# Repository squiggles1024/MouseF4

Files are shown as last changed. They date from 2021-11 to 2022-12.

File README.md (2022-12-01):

# Custom Gaming Mouse Project

One of my earlier embedded systems projects. A custom gaming mouse with up to 22 programmable buttons. The firmware is a bit rough around the edges, but I learned a lot about wired USB in the process of coding it.
I wrote a short Python script that communicates new settings to a USB endpoint dedicated to this purpose. 

This iteration implements 14 buttons, a mouse wheel, programmable DPI from 100 to 10000, a tricolored LED with 4 flashing modes, and button keybinds saved in an eeprom.
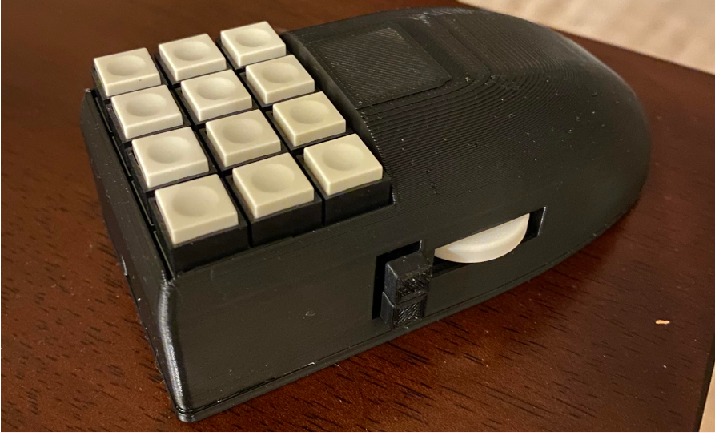
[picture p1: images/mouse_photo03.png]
Final Product


PCB is my own design featuring an STM32F4 microcontroller which I flashed using a J-Link SEGGER. The PMW3360 motion sensor was purchased as a COTs module. I would have liked to include this on the main PCBA, but the manufacturer was unrespsonsive to my emails and they don't stock the part openly at online retailers like digikey and mouser. The complete BOM and schematics are part of this repository
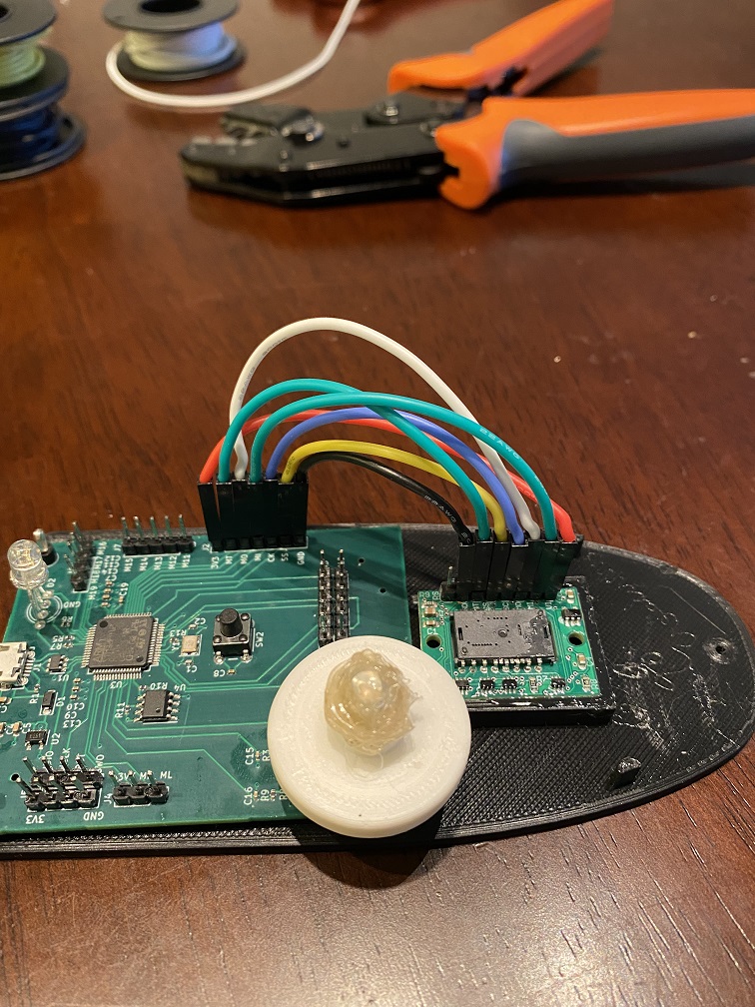
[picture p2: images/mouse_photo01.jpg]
PCB Design


The 3D printed housing (also my design) was glued to the base plate with E6000. Not a particularly robust mechanical design, but it worked for me. The main issue with this is that, because I didn't write a custom bootloader, the device can no longer be programmed again. This isn't a huge issue, but the mouse wheel you see in the photo is actually "backwards" (Scrolling forward will scroll down, and scrolling backward will scroll up). This is an easy firmware fix, but I can no longer access the JTAG pins or BOOT switch. 
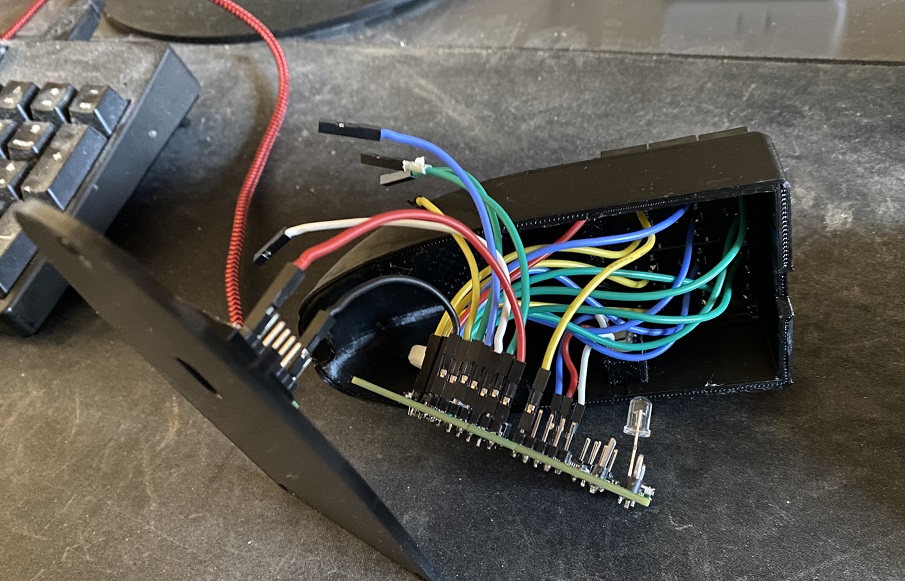
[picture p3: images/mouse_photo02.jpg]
Assembly


The LED can't really be seen in normal operation, though it can serve as a visual cue that new settings were successfully programmed when changing the keybinds using the python script.
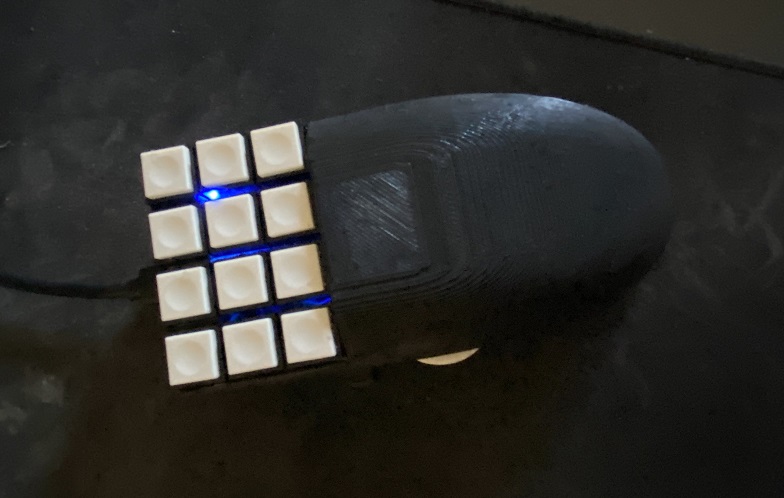
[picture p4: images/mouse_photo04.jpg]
LED


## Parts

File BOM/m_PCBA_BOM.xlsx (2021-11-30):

Comment | Designator | Footprint | JLCPCB Part #（optional） | Other PN
12pF | C1 | Capacitor_SMD:C_0402_1005Metric | C26406
12pF | C2 | Capacitor_SMD:C_0402_1005Metric | C26406
100nF | C3 | Capacitor_SMD:C_0603_1608Metric | C14663
1uF | C4 | Capacitor_SMD:C_0603_1608Metric | C15849
100nF | C5 | Capacitor_SMD:C_0603_1608Metric | C14663
1uF | C7 | Capacitor_SMD:C_0402_1005Metric | C52923
100nF | C8 | Capacitor_SMD:C_0402_1005Metric | C307331
100nF | C9 | Capacitor_SMD:C_0402_1005Metric | C307331
100nF | C10 | Capacitor_SMD:C_0402_1005Metric | C307331
100nF | C11 | Capacitor_SMD:C_0402_1005Metric | C307331
100nF | C12 | Capacitor_SMD:C_0402_1005Metric | C307331
100nF | C13 | Capacitor_SMD:C_0402_1005Metric | C307331
4.7u | C14 | Capacitor_SMD:C_0402_1005Metric | C23733
10nF | C15 | Capacitor_SMD:C_0402_1005Metric | C15195
10nF | C16 | Capacitor_SMD:C_0402_1005Metric | C15195
4.7u | C19 | Capacitor_SMD:C_0402_1005Metric | C23733
B5819W | D1 | Diode_SMD:D_SOD-123 | C8598
LED_RCGB | D2 | LED_THT:LED_D5.0mm-4_RGB_Wide_Pins |  | COM-00105
LED | D3 | Diode_SMD:D_0603_1608Metric | C2286
USB_B_Micro | J1 | Connector_USB:USB_Micro-B_Molex-105017-0001 | C132563
Conn_01x07 | J2 | Connector_PinHeader_2.54mm:PinHeader_1x07_P2.54mm_Vertical
Conn_02x06_Odd_Even | J3 | Connector_PinHeader_2.54mm:PinHeader_2x06_P2.54mm_Vertical
Conn_01x03 | J4 | Connector_PinHeader_2.54mm:PinHeader_1x03_P2.54mm_Vertical
Conn_02x04_Odd_Even | J5 | Connector_PinHeader_2.54mm:PinHeader_2x04_P2.54mm_Vertical
Conn_01x04 | J6 | Connector_PinHeader_2.54mm:PinHeader_1x04_P2.54mm_Vertical
Conn_01x05 | J7 | Connector_PinHeader_2.54mm:PinHeader_1x05_P2.54mm_Vertical
100k | R1 | Resistor_SMD:R_0402_1005Metric | C25741
10k | R2 | Resistor_SMD:R_0402_1005Metric | C25744
10k | R3 | Resistor_SMD:R_0402_1005Metric | C25744
10k | R4 | Resistor_SMD:R_0402_1005Metric | C25744
470 | R5 | Resistor_SMD:R_0402_1005Metric | C25117
470 | R6 | Resistor_SMD:R_0402_1005Metric | C25117
470 | R7 | Resistor_SMD:R_0402_1005Metric | C25117
10k | R8 | Resistor_SMD:R_0402_1005Metric | C25744
10k | R9 | Resistor_SMD:R_0402_1005Metric | C25744
4.7k | R10 | Resistor_SMD:R_0402_1005Metric | C25900
4.7k | R11 | Resistor_SMD:R_0402_1005Metric | C25900
510 | R12 | Resistor_SMD:R_0402_1005Metric | C25123
47 | R13 | Resistor_SMD:R_0402_1005Metric | C25117
SW_SPDT | SW1 | Button_Switch_SMD:SW_SPDT_PCM12 |  | PCM12SMTR
SW_Push | SW2 | Button_Switch_THT:SW_PUSH_6mm_H5mm |  | Any 6x5 push button
Rotary_Encoder_Switch | SW3 | Rotary_Encoder:RotaryEncoder_Alps_EC11E-Switch_Vertical_H20mm |  | EC11E09244AQ
USBLC6-2SC6 | U1 | Package_TO_SOT_SMD:SOT-23-6 | C7519
STLQ015M33R | U2 | Package_TO_SOT_SMD:SOT-23-5 | C136154
STM32F412RETx | U3 | Package_QFP:LQFP-64_10x10mm_P0.5mm | C89374
CAT24C32WI-GT3 | U4 | Package_SO:SOIC-8_3.9x4.9mm_P1.27mm | C81193
Crystal_GND24 | Y1 | Crystal:Crystal_SMD_3225-4Pin_3.2x2.5mm | C13738

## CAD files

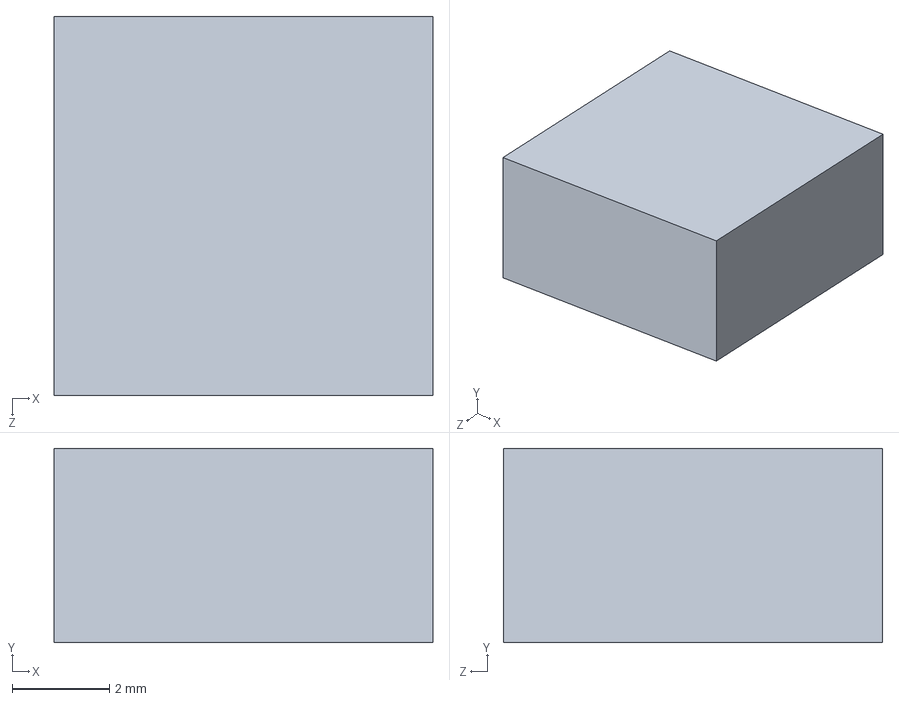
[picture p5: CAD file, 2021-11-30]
MCAD/keycaps3.SLDPRT
7.80 x 4.00 x 7.80 mm

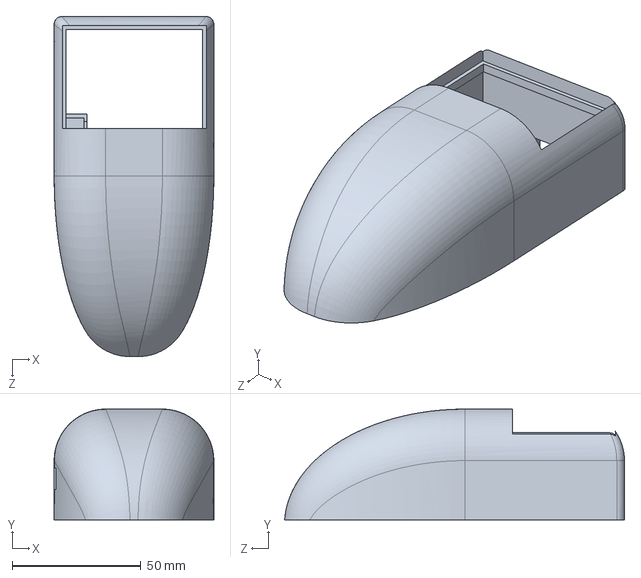
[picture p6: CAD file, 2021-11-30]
MCAD/mouse_housing.SLDPRT
62.0 x 43.0 x 132.0 mm

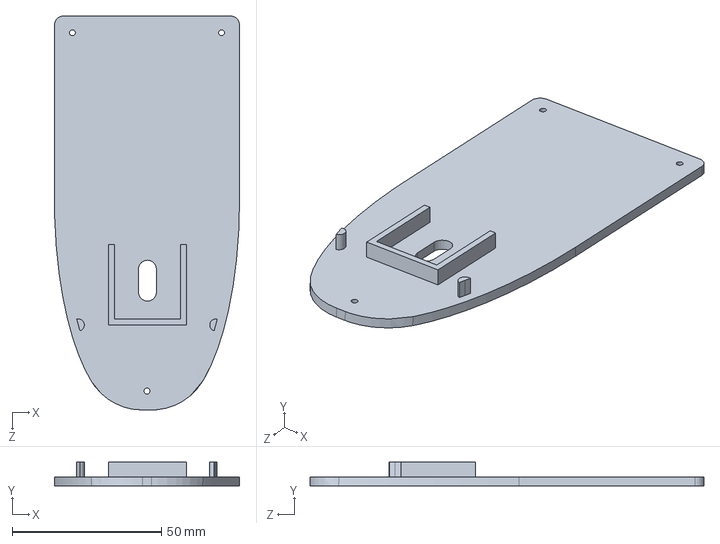
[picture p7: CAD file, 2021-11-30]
MCAD/mouse_base.SLDPRT
62.0 x 8.00 x 132.0 mm

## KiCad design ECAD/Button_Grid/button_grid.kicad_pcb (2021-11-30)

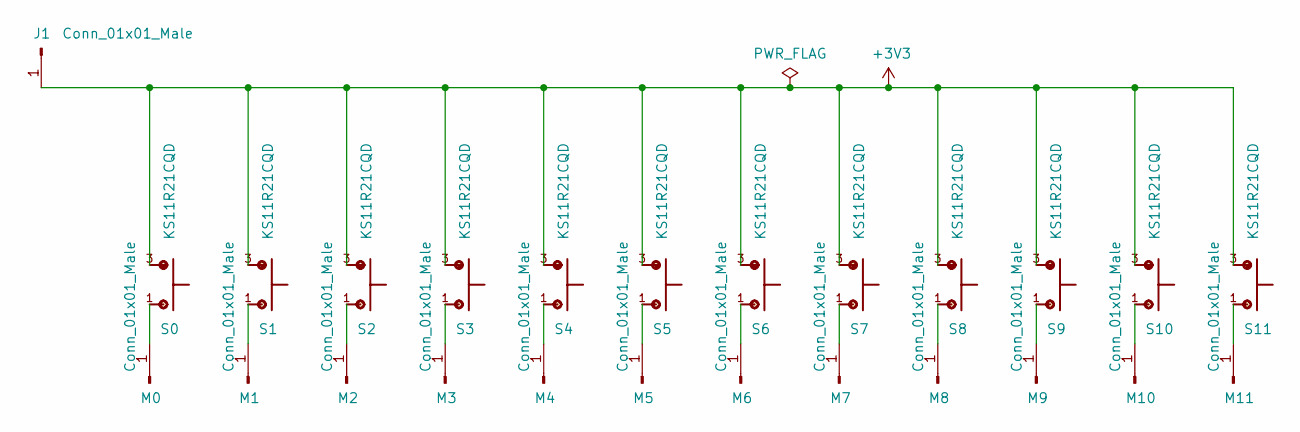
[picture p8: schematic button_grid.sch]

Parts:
J1: Conn_01x01_Male; PinHeader_1x01_P2.54mm_Vertical
M0, M1, M2, M3, M4, M5, M6, M7, M8, M9, M10, M11: Conn_01x01_Male; PinHeader_1x01_P2.54mm_Vertical
S0, S1, S2, S3, S4, S5, S6, S7, S8, S9, S10, S11: KS11R21CQD; SW_KS11R21CQD

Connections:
+3V3: J1.1, S0.3, S1.3, S2.3, S3.3, S4.3, S5.3, S6.3, S7.3, S8.3, S9.3, S10.3, S11.3
unnamed: M0.1, S0.1
unnamed: M1.1, S1.1
unnamed: M2.1, S2.1
unnamed: M3.1, S3.1
unnamed: M4.1, S4.1
unnamed: M5.1, S5.1
unnamed: M6.1, S6.1
unnamed: M7.1, S7.1
unnamed: M8.1, S8.1
unnamed: M9.1, S9.1
unnamed: M10.1, S10.1
unnamed: M11.1, S11.1

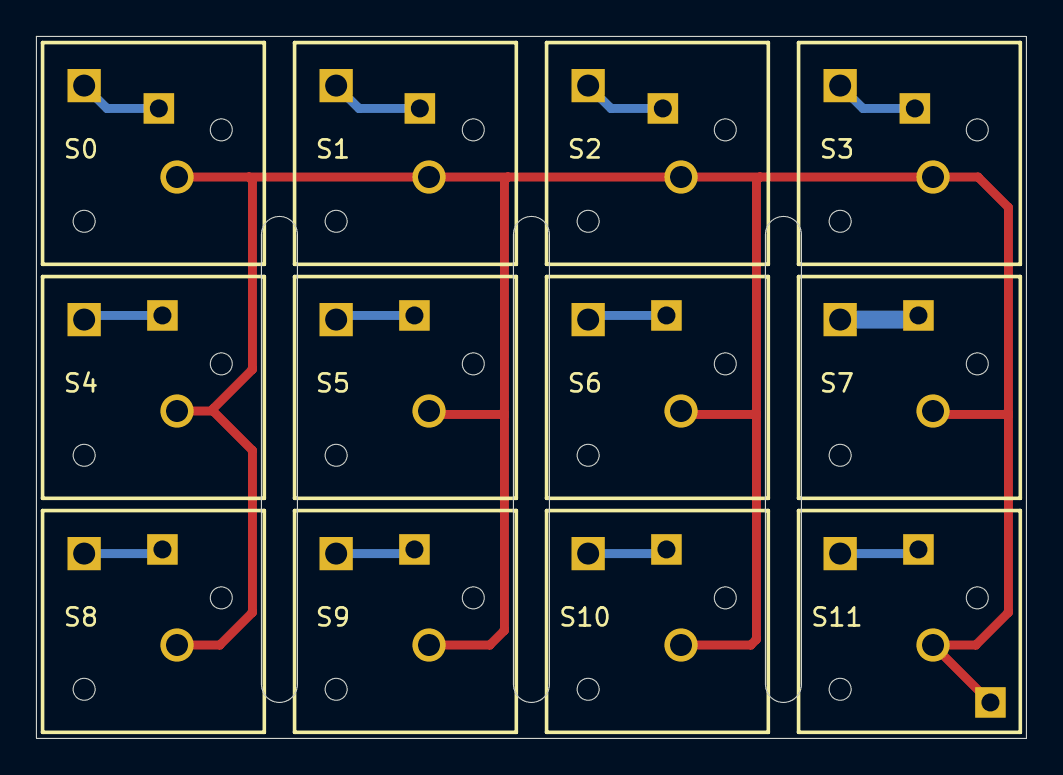
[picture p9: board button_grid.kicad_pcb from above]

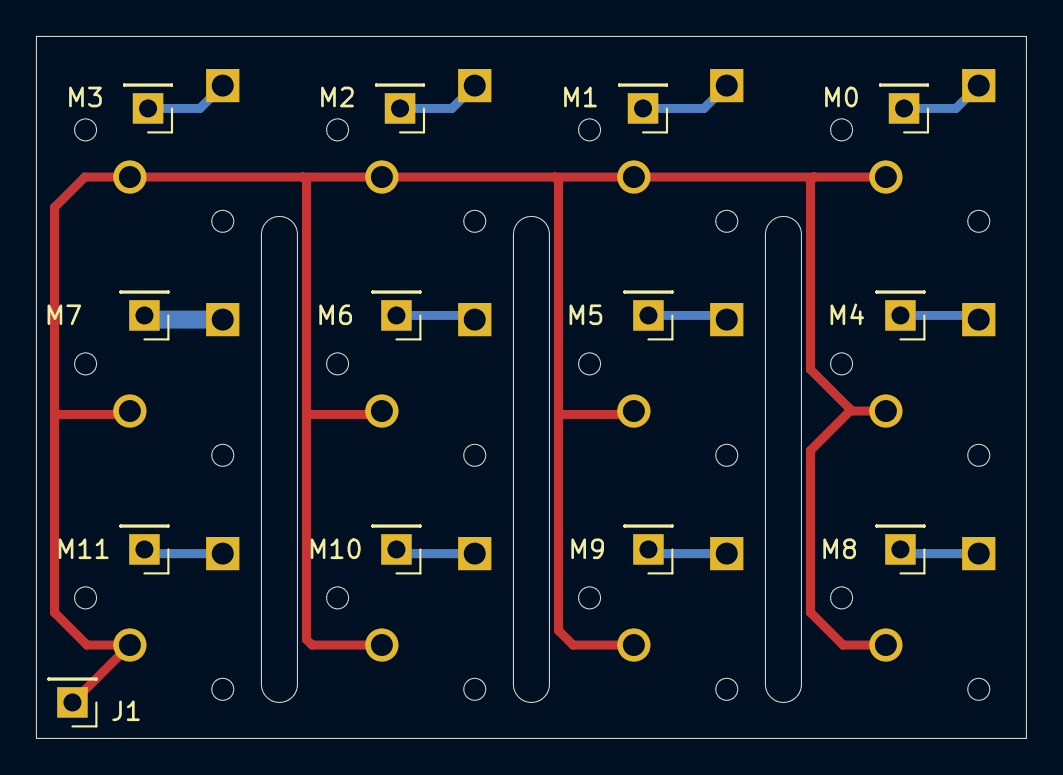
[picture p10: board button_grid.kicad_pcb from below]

Board: 2 copper layers, 55.0 x 39.0 mm, 25 parts (13 on the bottom side), 13 nets.

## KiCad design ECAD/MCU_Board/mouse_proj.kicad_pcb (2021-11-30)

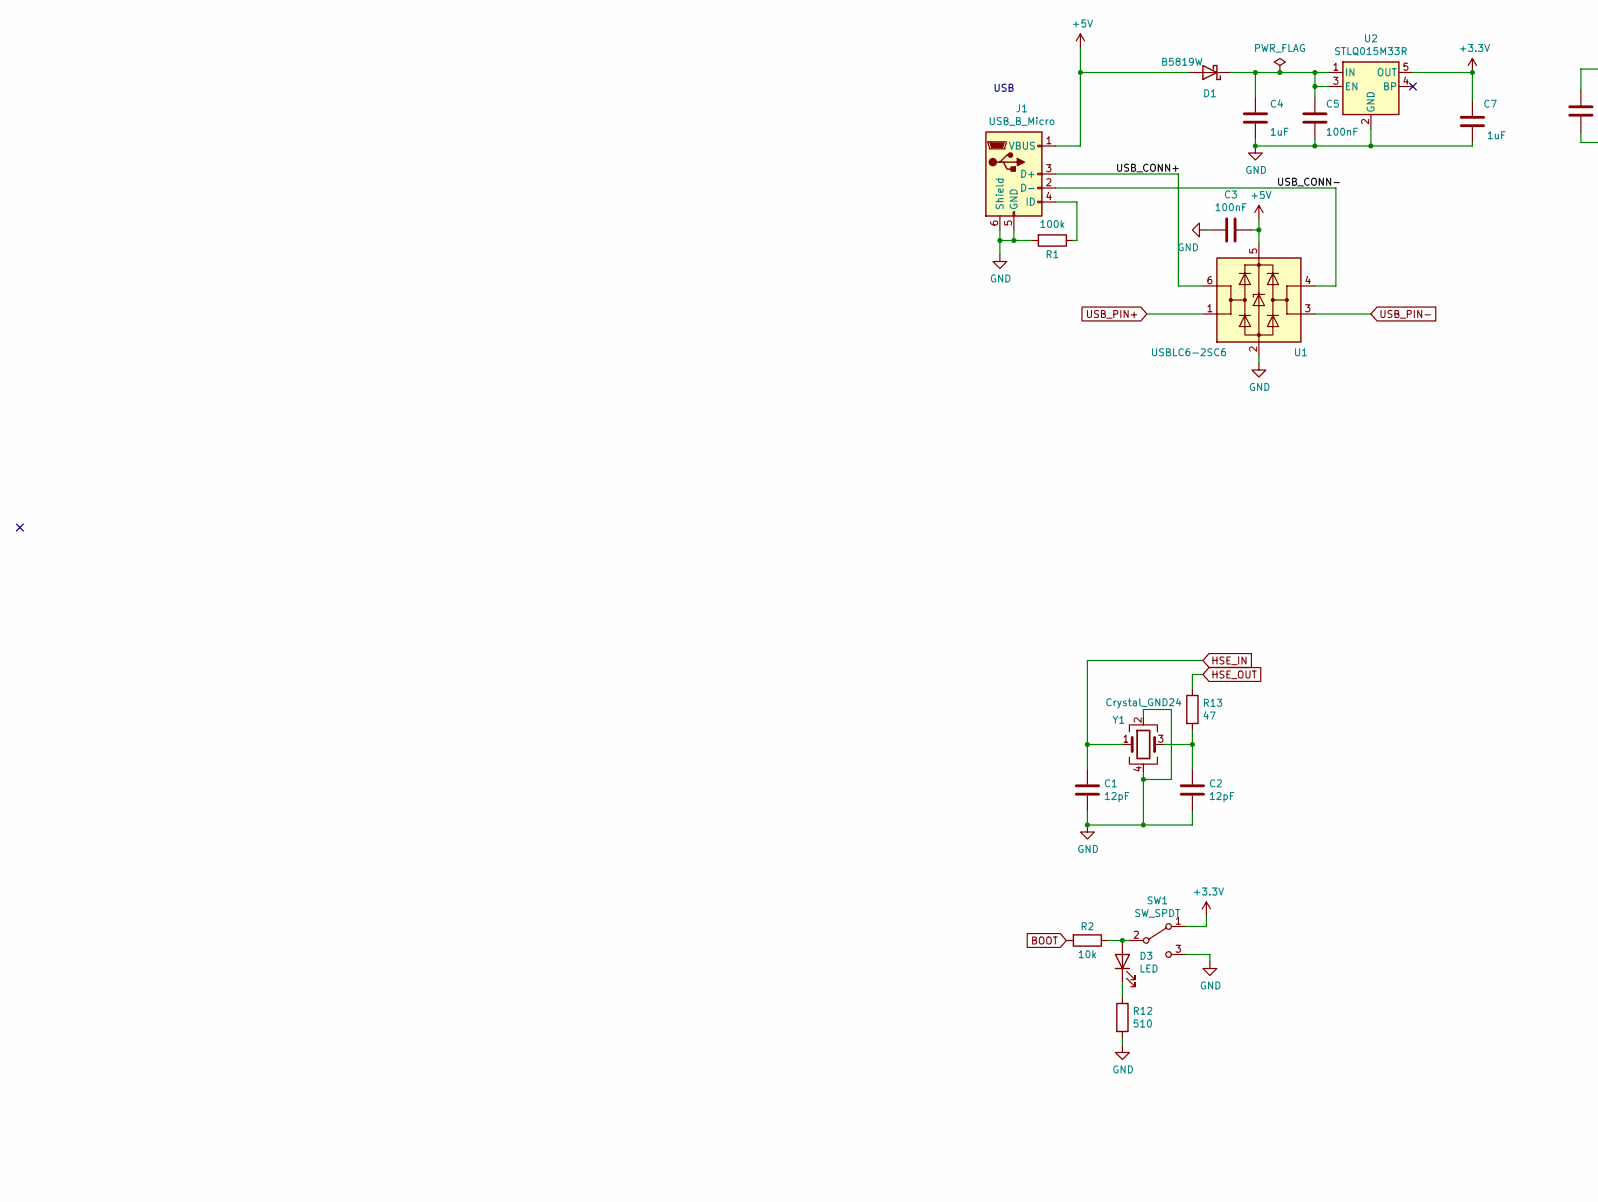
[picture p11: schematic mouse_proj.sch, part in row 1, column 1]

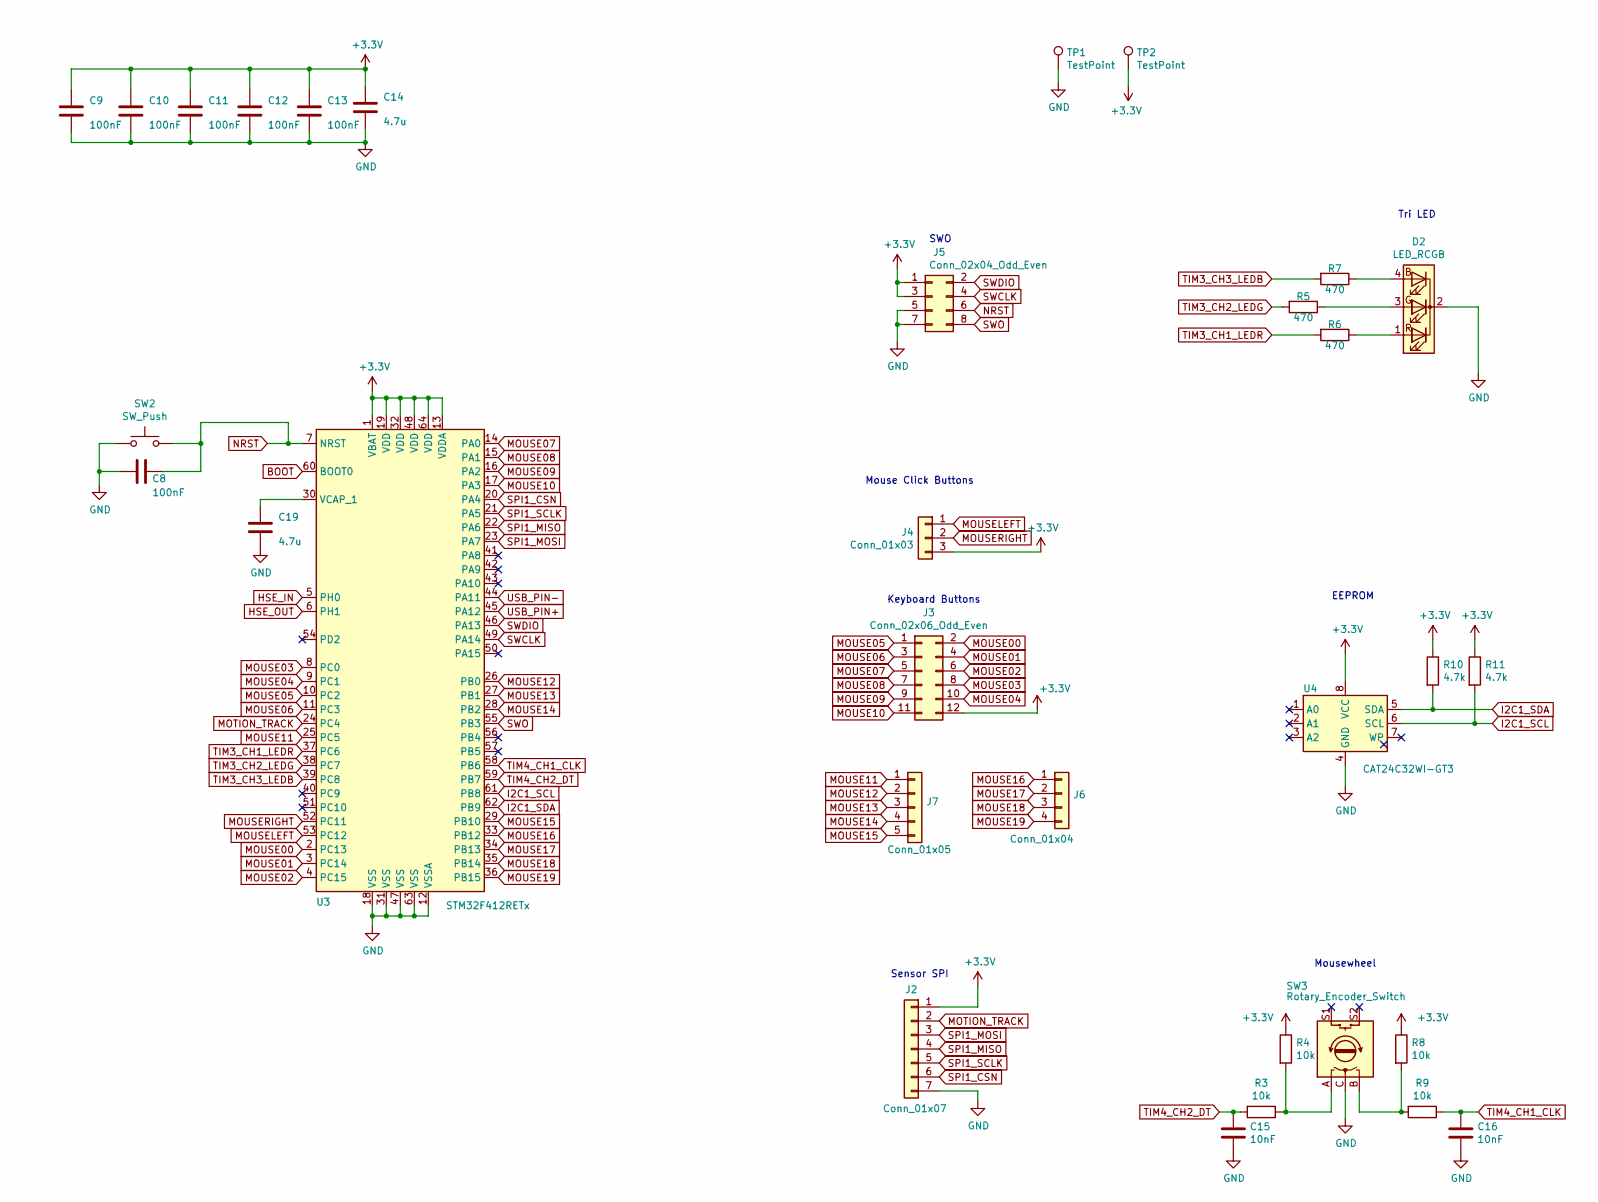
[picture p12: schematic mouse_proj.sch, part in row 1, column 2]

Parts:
C1, C2: 12pF; C_0402_1005Metric; LCSC Part # C26406
C3, C5: 100nF; C_0603_1608Metric; LCSC Part # C14663
C4: 1uF; C_0603_1608Metric; LCSC Part # C15849
C7: 1uF; C_0402_1005Metric; LCSC Part # C52923
C8, C9, C10, C11, C12, C13: 100nF; C_0402_1005Metric; LCSC Part # C307331
C14, C19: 4.7u; C_0402_1005Metric; LCSC Part # C23733
C15, C16: 10nF; C_0402_1005Metric; LCSC Part # C15195
D1: B5819W; D_SOD-123; LCSC Part # C8598
D2: LED_RCGB; LED_D5.0mm-4_RGB_Wide_Pins
D3: LED; D_0603_1608Metric; LCSC Part # C2286
J1: USB_B_Micro; USB_Micro-B_Molex-105017-0001; LCSC Part # C132563
J2: Conn_01x07; PinHeader_1x07_P2.54mm_Vertical
J3: Conn_02x06_Odd_Even; PinHeader_2x06_P2.54mm_Vertical
J4: Conn_01x03; PinHeader_1x03_P2.54mm_Vertical
J5: Conn_02x04_Odd_Even; PinHeader_2x04_P2.54mm_Vertical
J6: Conn_01x04; PinHeader_1x04_P2.54mm_Vertical
J7: Conn_01x05; PinHeader_1x05_P2.54mm_Vertical
R1: 100k; R_0402_1005Metric; LCSC Part # C25741
R2, R3, R4, R8, R9: 10k; R_0402_1005Metric; LCSC Part # C25744
R5, R6, R7: 470; R_0402_1005Metric; LCSC Part # C25117
R10, R11: 4.7k; R_0402_1005Metric; LCSC Part # C25900
R12: 510; R_0402_1005Metric; LCSC Part # C25123
R13: 47; R_0402_1005Metric; LCSC Part # C25117
SW1: SW_SPDT; SW_SPDT_PCM12
SW2: SW_Push; SW_PUSH_6mm_H5mm
SW3: Rotary_Encoder_Switch; RotaryEncoder_Alps_EC11E-Switch_Vertical_H20mm
TP1, TP2: TestPoint; TestPoint_THTPad_D3.0mm_Drill1.5mm
U1: USBLC6-2SC6; SOT-23-6; LCSC Part # C7519
U2: STLQ015M33R; SOT-23-5; LCSC Part # C136154
U3: STM32F412RETx; LQFP-64_10x10mm_P0.5mm; LCSC Part # C89374
U4: CAT24C32WI-GT3; SOIC-8_3.9x4.9mm_P1.27mm; LCSC Part # C81193
Y1: Crystal_GND24; Crystal_SMD_3225-4Pin_3.2x2.5mm; LCSC Part # C13738

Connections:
+3V3: C7.1, C9.1, C10.1, C11.1, C12.1, C13.1, C14.1, J2.1, J3.12, J4.3, J5.1, J5.3, R4.1, R8.1, R10.1, R11.1, SW1.1 (A), TP2.1, U2.5 (OUT), U3.1 (VBAT), U3.13 (VDDA), U3.19 (VDD), U3.32 (VDD), U3.48 (VDD), U3.64 (VDD), U4.8 (VCC)
+5V: C3.1, D1.2 (A), J1.1 (VBUS), U1.5 (VBUS)
/USB_CONN+: J1.3 (D+), U1.6 (I/O1)
/USB_CONN-: J1.2 (D-), U1.4 (I/O2)
BOOT: R2.2, U3.60 (BOOT0)
GND: C1.2, C2.2, C3.2, C4.2, C5.2, C7.2, C8.2, C9.2, C10.2, C11.2, C12.2, C13.2, C14.2, C15.2, C16.2, C19.2, D2.2 (K), J1.5 (GND), J1.6 (Shield), J2.7, J5.5, J5.7, R1.2, R12.2, SW1.3 (C), SW2.1, SW3.C, TP1.1, U1.2 (GND), U2.2 (GND), U3.12 (VSSA), U3.18 (VSS), U3.31 (VSS), U3.47 (VSS), U3.63 (VSS), U4.4 (GND), Y1.2, Y1.4
HSE_IN: C1.1, U3.5 (PH0), Y1.1
HSE_OUT: R13.1, U3.6 (PH1)
I2C1_SCL: R11.2, U3.61 (PB8), U4.6 (SCL)
I2C1_SDA: R10.2, U3.62 (PB9), U4.5 (SDA)
MOTION_TRACK: J2.2, U3.24 (PC4)
MOUSE00: J3.2, U3.2 (PC13)
MOUSE01: J3.4, U3.3 (PC14)
MOUSE02: J3.6, U3.4 (PC15)
MOUSE03: J3.8, U3.8 (PC0)
MOUSE04: J3.10, U3.9 (PC1)
MOUSE05: J3.1, U3.10 (PC2)
MOUSE06: J3.3, U3.11 (PC3)
MOUSE07: J3.5, U3.14 (PA0)
MOUSE08: J3.7, U3.15 (PA1)
MOUSE09: J3.9, U3.16 (PA2)
MOUSE10: J3.11, U3.17 (PA3)
MOUSE11: J7.1, U3.25 (PC5)
MOUSE12: J7.2, U3.26 (PB0)
MOUSE13: J7.3, U3.27 (PB1)
MOUSE14: J7.4, U3.28 (PB2)
MOUSE15: J7.5, U3.29 (PB10)
MOUSE16: J6.1, U3.33 (PB12)
MOUSE17: J6.2, U3.34 (PB13)
MOUSE18: J6.3, U3.35 (PB14)
MOUSE19: J6.4, U3.36 (PB15)
MOUSELEFT: J4.1, U3.53 (PC12)
MOUSERIGHT: J4.2, U3.52 (PC11)
NRST: C8.1, J5.6, SW2.2, U3.7 (NRST)
unnamed: C2.1, R13.2, Y1.3
unnamed: C4.1, C5.1, D1.1 (K), U2.1 (IN), U2.3 (EN)
unnamed: C19.1, U3.30 (VCAP_1)
unnamed: D2.1 (RA), R6.1
unnamed: D2.3 (GA), R5.1
unnamed: D2.4 (BA), R7.1
unnamed: D3.1 (K), R12.1
unnamed: D3.2 (A), R2.1, SW1.2 (B)
unnamed: J1.4 (ID), R1.1
unnamed: R3.1, R4.2, SW3.A
unnamed: R8.2, R9.2, SW3.B
SPI1_CSN: J2.6, U3.20 (PA4)
SPI1_MISO: J2.4, U3.22 (PA6)
SPI1_MOSI: J2.3, U3.23 (PA7)
SPI1_SCLK: J2.5, U3.21 (PA5)
SWCLK: J5.4, U3.49 (PA14)
SWDIO: J5.2, U3.46 (PA13)
SWO: J5.8, U3.55 (PB3)
TIM3_CH1_LEDR: R6.2, U3.37 (PC6)
TIM3_CH2_LEDG: R5.2, U3.38 (PC7)
TIM3_CH3_LEDB: R7.2, U3.39 (PC8)
TIM4_CH1_CLK: C16.1, R9.1, U3.58 (PB6)
TIM4_CH2_DT: C15.1, R3.2, U3.59 (PB7)
USB_PIN+: U1.1 (I/O1), U3.45 (PA12)
USB_PIN-: U1.3 (I/O2), U3.44 (PA11)

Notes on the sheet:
SWO
Tri LED
EEPROM
Mousewheel
Keyboard Buttons
Mouse Click Buttons
Sensor SPI
USB

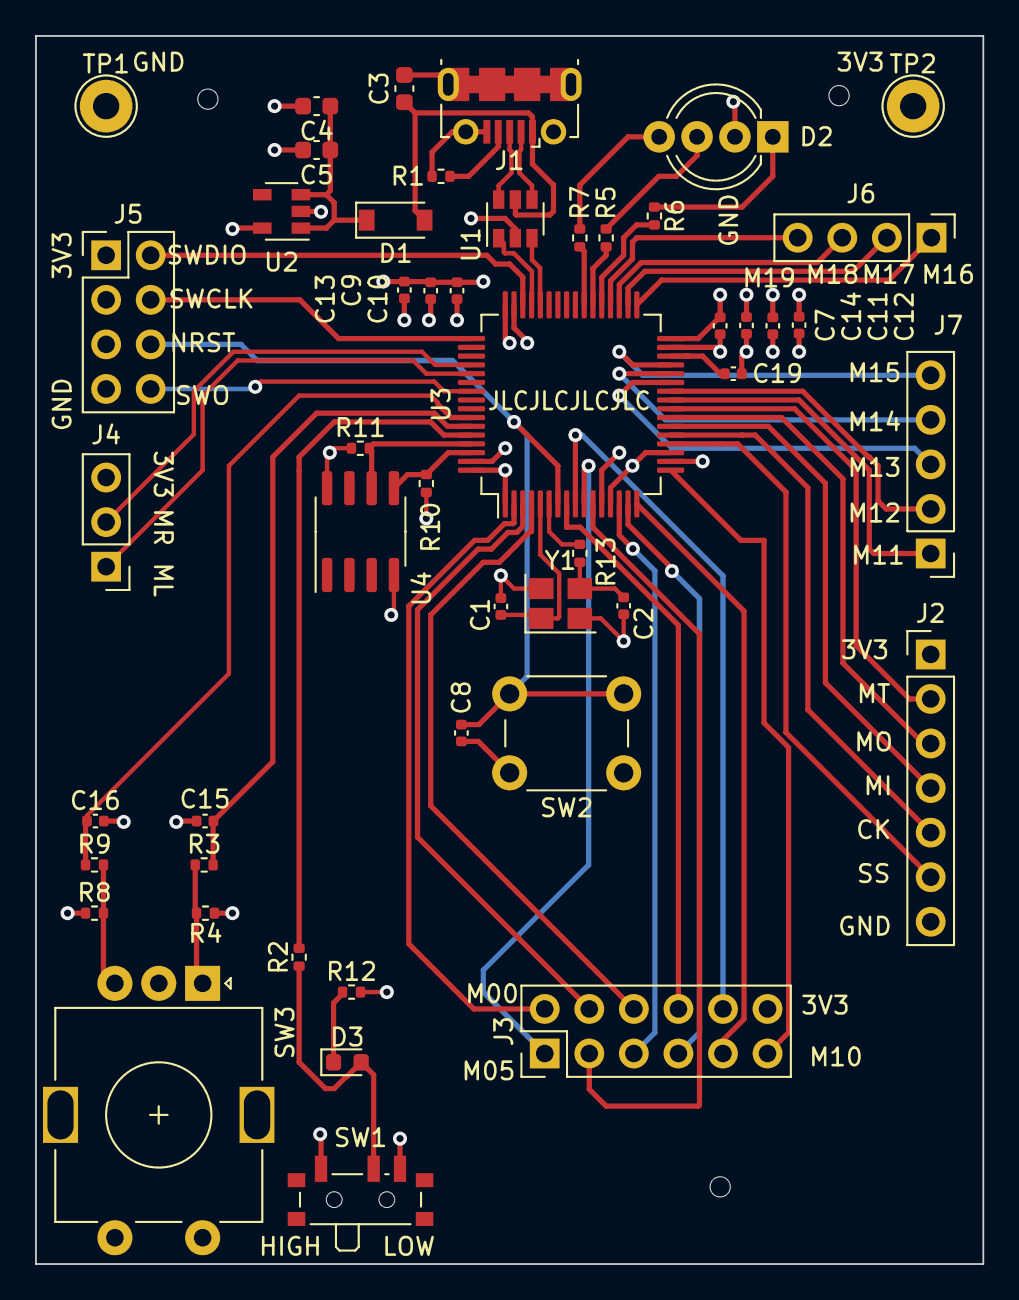
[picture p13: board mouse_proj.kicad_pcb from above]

Board: 4 copper layers, 54.0 x 70.0 mm, 49 parts (0 on the bottom side), 59 nets.

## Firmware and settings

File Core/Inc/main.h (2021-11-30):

#ifndef __MAIN_H
#define __MAIN_H

#ifdef __cplusplus
extern "C" {
#endif

#include "stm32f4xx_hal.h"


void HAL_TIM_MspPostInit(TIM_HandleTypeDef *htim);

void Error_Handler(void);

#define MOUSE00_Pin GPIO_PIN_13
#define MOUSE00_GPIO_Port GPIOC
#define MOUSE01_Pin GPIO_PIN_14
#define MOUSE01_GPIO_Port GPIOC
#define MOUSE02_Pin GPIO_PIN_15
#define MOUSE02_GPIO_Port GPIOC
#define MOUSE03_Pin GPIO_PIN_0
#define MOUSE03_GPIO_Port GPIOC
#define MOUSE04_Pin GPIO_PIN_1
#define MOUSE04_GPIO_Port GPIOC
#define MOUSE05_Pin GPIO_PIN_2
#define MOUSE05_GPIO_Port GPIOC
#define MOUSE06_Pin GPIO_PIN_3
#define MOUSE06_GPIO_Port GPIOC
#define MOUSE07_Pin GPIO_PIN_0
#define MOUSE07_GPIO_Port GPIOA
#define MOUSE08_Pin GPIO_PIN_1
#define MOUSE08_GPIO_Port GPIOA
#define MOUSE09_Pin GPIO_PIN_2
#define MOUSE09_GPIO_Port GPIOA
#define MOUSE10_Pin GPIO_PIN_3
#define MOUSE10_GPIO_Port GPIOA
#define SENSOR_CSN_GPIO_Port GPIOA
#define SENSOR_CSN_Pin GPIO_PIN_4
#define MOTION_TRACK_Pin GPIO_PIN_4
#define MOTION_TRACK_GPIO_Port GPIOC
#define MOUSE11_Pin GPIO_PIN_5
#define MOUSE11_GPIO_Port GPIOC
#define MOUSE12_Pin GPIO_PIN_0
#define MOUSE12_GPIO_Port GPIOB
#define MOUSE13_Pin GPIO_PIN_1
#define MOUSE13_GPIO_Port GPIOB
#define MOUSE14_Pin GPIO_PIN_2
#define MOUSE14_GPIO_Port GPIOB
#define MOUSE15_Pin GPIO_PIN_10
#define MOUSE15_GPIO_Port GPIOB
#define MOUSE16_Pin GPIO_PIN_12
#define MOUSE16_GPIO_Port GPIOB
#define MOUSE17_Pin GPIO_PIN_13
#define MOUSE17_GPIO_Port GPIOB
#define MOUSE18_Pin GPIO_PIN_14
#define MOUSE18_GPIO_Port GPIOB
#define MOUSE19_Pin GPIO_PIN_15
#define MOUSE19_GPIO_Port GPIOB
#define TIM3_CH1_LEDR_Pin GPIO_PIN_6
#define TIM3_CH1_LEDR_GPIO_Port GPIOC
#define TIM3_CH2_LEDG_Pin GPIO_PIN_7
#define TIM3_CH2_LEDG_GPIO_Port GPIOC
#define TIM3_CH3_LEDB_Pin GPIO_PIN_8
#define TIM3_CH3_LEDB_GPIO_Port GPIOC
#define MOUSERIGHT_Pin GPIO_PIN_11
#define MOUSERIGHT_GPIO_Port GPIOC
#define MOUSELEFT_Pin GPIO_PIN_12
#define MOUSELEFT_GPIO_Port GPIOC
#define TIM4_CH1_CLK_Pin GPIO_PIN_7
#define TIM4_CH1_CLK_GPIO_Port GPIOB
#define TIM4_CH2_DT_Pin GPIO_PIN_6
#define TIM4_CH2_DT_GPIO_Port GPIOB



#define LED_TIM htim3
#define MOUSEWHEEL_TIM htim4
#define MOUSESENSOR_SPI hspi1
#define US_DELAY_TIM htim6
#define SETTINGS_EEPROM_I2C hi2c1
//2 bytes for DPI, 1 byte for LED Cycle Mode, 1 byte for pulse length, 3 bytes for LED Colors,
#define TOTAL_MOUSE_BUTTONS (22U)
#define TOTAL_SETTINGS (TOTAL_MOUSE_BUTTONS + 2 + 1 + 1 + 3)
#define DPI_LO_BYTE_INDEX (TOTAL_MOUSE_BUTTONS)
#define DPI_HI_BYTE_INDEX (TOTAL_MOUSE_BUTTONS + 1)
#define LED_MODE_INDEX (TOTAL_MOUSE_BUTTONS + 2)
#define LED_PULSE_LENGTH_INDEX (TOTAL_MOUSE_BUTTONS + 3)
#define LED_RED_INDEX (TOTAL_MOUSE_BUTTONS + 4)
#define LED_GREEN_INDEX (TOTAL_MOUSE_BUTTONS + 5)
#define LED_BLUE_INDEX (TOTAL_MOUSE_BUTTONS + 6)

#define LED_RED_CH TIM_CHANNEL_1
#define LED_GREEN_CH TIM_CHANNEL_2
#define LED_BLUE_CH TIM_CHANNEL_3

/* USER CODE END Private defines */

#ifdef __cplusplus
}
#endif

#endif /* __MAIN_H */

/************************ (C) COPYRIGHT STMicroelectronics *****END OF FILE****/

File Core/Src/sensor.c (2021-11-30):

/*
 * sensor.c
 *
 *  Created on: Oct 19, 2021
 *      Author: evanl
 */
#include <sensor.h>
#include <main.h>
#include <sensor_firmware.h>
#include "delay_timer.h"
#include "stm32f4xx_hal_spi.h"
#include "stm32f4xx_hal_gpio.h"

extern TIM_HandleTypeDef US_DELAY_TIM;
static void set_csn_high(sensor_t* sensor);
static void set_csn_low(sensor_t* sensor);
static sensor_status_t sensor_write(sensor_t* sensor,uint8_t address, uint8_t data);
static uint8_t sensor_read(sensor_t* sensor,uint8_t address);

static void sensor_srom_download(sensor_t* sensor);

sensor_status_t sensor_init(sensor_t* sensor){
	HAL_TIM_Base_Start(&US_DELAY_TIM);
    /*
    load the firmware using these steps: set CS high, set it low, set it high again. write 0x5A to Power_Up_Reset reg, wait 50ms at least
    Read regs Motion, Delta_X_L, Delta_X_H, Delta_Y_L, Delta_Y_H, Download SROM, config other registers
    */
	set_csn_high(sensor);
	set_csn_low(sensor);
	set_csn_high(sensor);

	uint8_t data_dummy = 0x5A;
	sensor_write(sensor,Power_Up_Reset,data_dummy);
	HAL_Delay(50);

	if(sensor_read(sensor, Motion) == sensor_error){
		return sensor_error;
	}
	if(sensor_read(sensor, Delta_X_L) == sensor_error){
		return sensor_error;
	}
	if(sensor_read(sensor, Delta_X_H) == sensor_error){
		return sensor_error;
	}
	if(sensor_read(sensor, Delta_Y_L) == sensor_error){
		return sensor_error;
	}
	if(sensor_read(sensor, Delta_Y_H) == sensor_error){
		return sensor_error;
	}

    sensor_srom_download(sensor);

    HAL_Delay(10);
   sensor_setdpi(sensor, DEFAULT_DPI);



	return sensor_ok;
}

static void set_csn_high(sensor_t* sensor){
	HAL_GPIO_WritePin(sensor->CSN_GPIOx, sensor->csn_pin, GPIO_PIN_SET);
}

static void set_csn_low(sensor_t* sensor){
	HAL_GPIO_WritePin(sensor->CSN_GPIOx, sensor->csn_pin, GPIO_PIN_RESET);
}

static sensor_status_t sensor_write(sensor_t* sensor,uint8_t address, uint8_t cmd){
	uint8_t write_address = address | WRITE_MODE_MSK;
	set_csn_low(sensor);

	if(HAL_SPI_Transmit(sensor->HSPIx, &write_address, 1, TIMEOUT) == HAL_TIMEOUT){
		return sensor_error;
	}

	if(HAL_SPI_Transmit(sensor->HSPIx, &cmd, 1, TIMEOUT)== HAL_TIMEOUT){
		return sensor_error;
	}

    delay_us(20);
    set_csn_high(sensor);
    delay_us(50);
    return sensor_ok;
}

static sensor_status_t sensor_read(sensor_t* sensor,uint8_t address){
    uint8_t data = 0;
    uint8_t read_address = address & READ_MODE_MSK;
    set_csn_low(sensor);
    if(HAL_SPI_Transmit(sensor->HSPIx, &read_address, 1, TIMEOUT) == HAL_TIMEOUT){
    	return sensor_error;
    }
    delay_us(50);
    if(HAL_SPI_Receive(sensor->HSPIx, &data, 1, TIMEOUT) == HAL_TIMEOUT){
    	return sensor_error;
    }
    delay_us(1);
    set_csn_high(sensor);
    delay_us(19);
    sensor->fetched_data = data;
    return sensor_ok;
}

static void sensor_srom_download(sensor_t* sensor){
	uint8_t dummy = 0x20;
    sensor_write(sensor,Config2,dummy);

    dummy = 0x1d;
    sensor_write(sensor,SROM_Enable, dummy);

    HAL_Delay(10);

    dummy = 0x18;
    sensor_write(sensor,SROM_Enable, dummy);

    set_csn_low(sensor);

    dummy = SROM_Load_Burst | 0x80;
    HAL_SPI_Transmit(sensor->HSPIx,&dummy,1,TIMEOUT);

    delay_us(15);
    for(uint32_t i = 0; i < firmware_length; i++){
        dummy = firmware_data[i];
        HAL_SPI_Transmit(sensor->HSPIx, &dummy,1,TIMEOUT);
        delay_us(15);
    }
    set_csn_high(sensor);
}

sensor_status_t sensor_update_position(sensor_t* sensor){

	if(HAL_GPIO_ReadPin(sensor->MT_GPIOx, sensor->motion_track_pin) != MOTION_DETECTED){
		sensor->motion_x = 0;
		sensor->motion_y = 0;
		return sensor_ok;
	}

	if(sensor_write(sensor,Motion,0x1) == sensor_error){
		return sensor_error;
	}

	if(sensor_read(sensor,Motion) == sensor_error){
		return sensor_error;
	}

	if(sensor_read(sensor,Delta_X_L) == sensor_error){
		return sensor_error;
	} else {
		sensor->motion_x = sensor->fetched_data;
	}

	if(sensor_read(sensor,Delta_X_H) == sensor_error){
		return sensor_error;
	}

	if(sensor_read(sensor,Delta_Y_L) == sensor_error){
		return sensor_error;
	} else {
		sensor->motion_y = sensor->fetched_data;
	}

	if(sensor_read(sensor,Delta_Y_H) == sensor_error){
		return sensor_error;
	}

	return sensor_ok;
}

sensor_status_t sensor_setdpi(sensor_t* sensor, uint16_t DPI){
	if(DPI < DPI_MIN || DPI > DPI_MAX){
		return sensor_error;
	}
	if(DPI % 100 != 0){
		return sensor_error;
	}
	if(sensor_write(sensor, Config1, (DPI - 100) / 100) == sensor_error){
		return sensor_error;
	}
	return sensor_ok;
}

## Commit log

2021-11-30 Added BOM
    [m_PCBA_BOM.xlsx]
2021-11-30 Added Mechanical models
    [keycaps3.SLDPRT, mouse_base.SLDPRT, mouse_housing.SLDPRT]
2021-11-30 Added ECAD Models
    [button_grid-B_Cu.gbr, button_grid-B_Mask.gbr, button_grid-B_Paste.gbr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]
